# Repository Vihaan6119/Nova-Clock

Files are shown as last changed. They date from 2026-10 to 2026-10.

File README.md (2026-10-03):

# Nova Clock

Nova Clock is a custom desktop alarm clock built around a Seeed Studio XIAO ESP32-C3. It has a 2.25-inch TFT display, four mechanical keyboard switches, a piezo buzzer, a custom PCB, and a custom 3D-printed enclosure. The PCB, enclosure, and firmware were all designed as part of the same project so the electronics and the case fit together as one system.

## Why I made it

I wanted to build a project that was more than just a basic clock. I wanted to learn how a real hardware product comes together, from designing the PCB and enclosure to writing the firmware and planning how the final device would actually be used.
I also wanted the clock to be something I could keep improving later, especially the display styles, alarms, sounds, and the way it can be configured from another device.

## Project

The final design uses a custom PCB with the XIAO ESP32-C3 as the main controller. The four switches are used for local controls, while the TFT is used for the clock and other information. The buzzer provides startup and alarm sounds.

The enclosure was designed around the PCB so the board can be mounted securely while still leaving access to the USB port, display, switches, and buzzer. The display is held in place with a separate retainer so it can be removed without having to glue it into the case.

## How I planned the firmware

The firmware is included in the repository as a working prototype for the hardware design. The main idea is:

- show a short Nova Clock startup animation
- play a startup beep
- display the current time
- use the buttons for local clock and alarm controls
- store alarm settings on the ESP32-C3
- connect the clock to Wi-Fi
- provide a local web interface for changing alarm and display settings
- support different display styles and alarm sound patterns

The physical hardware is not available while the firmware was being made, so the final hardware behavior will be verified after the components arrive.

## Project images

### Case fit

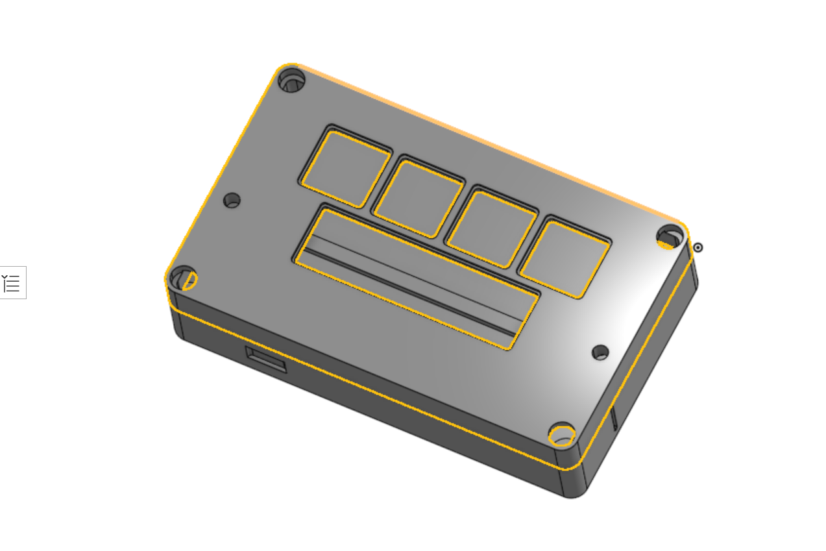
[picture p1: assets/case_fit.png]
Nova Clock Case Fit


### PCB

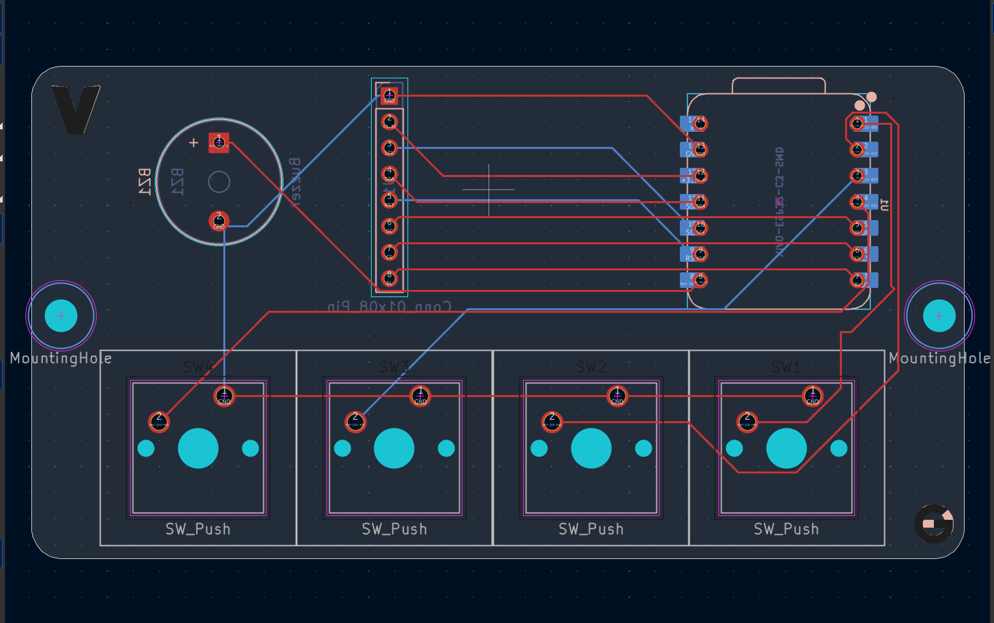
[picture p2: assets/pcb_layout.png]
Nova Clock PCB


### Schematic / wiring

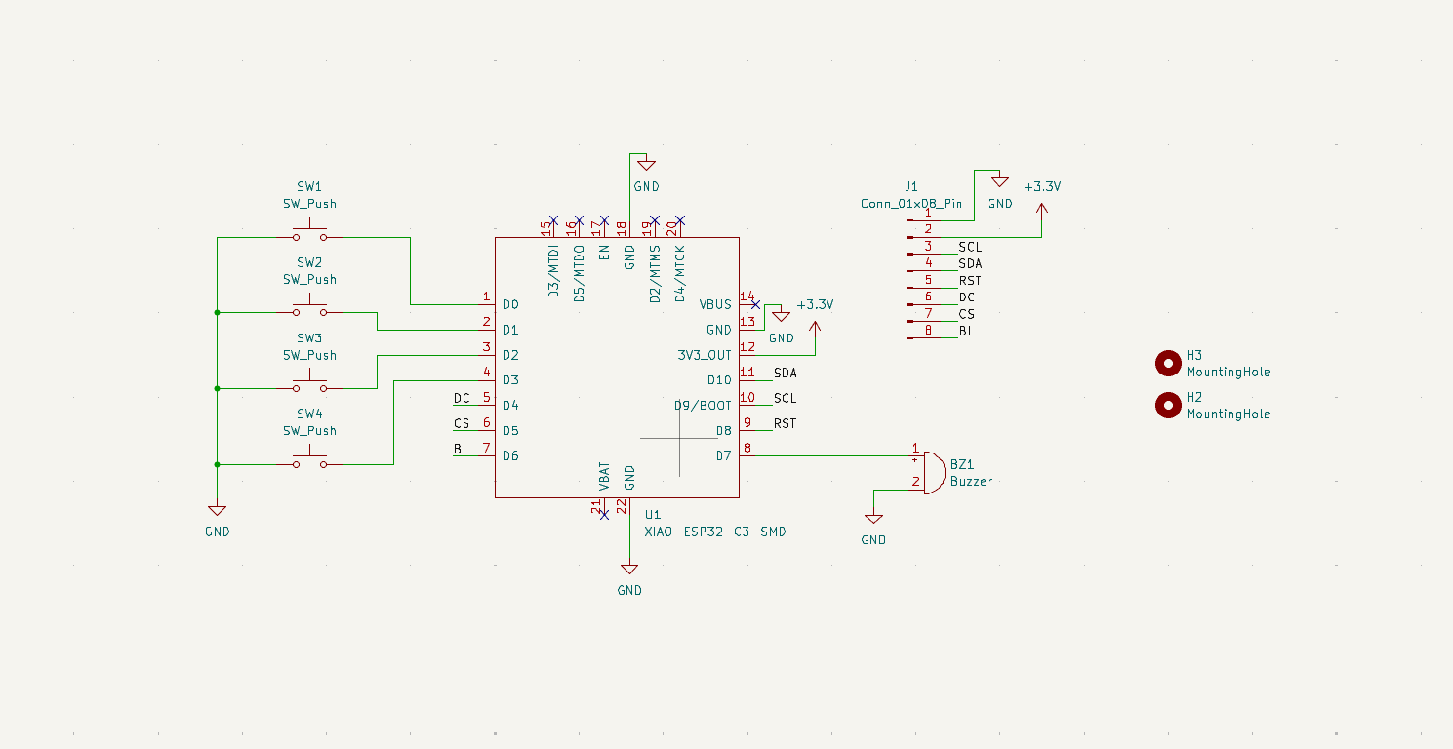
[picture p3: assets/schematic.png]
Nova Clock Schematic


The display is connected to the PCB using the 8-pin header and jumper wires included in the kit.

## Files

The repository contains the KiCad project and PCB source files, the CAD source and STEP assembly, the firmware, manufacturing files, and the project images.

- `PCB/` - KiCad project, schematic, PCB layout, and manufacturing files
- `CAD/` - enclosure source files and final STEP assembly
- `Firmware/` - Nova Clock firmware
- `Production/` - production/export files
- `assets/` - screenshots and project images

## Bill of Materials

| Component | Quantity Used | Quantity in Kit | Description | Link |
|---|---:|---:|---|---|
| Seeed Studio XIAO ESP32-C3 | 1 | 1 | Main microcontroller | [Seeed documentation](https://wiki.seeedstudio.com/XIAO_ESP32C3_Getting_Started/) |
| MX-style keyboard switch | 4 | 12 | Mechanical switches | [Switch specification](https://cdn.shopify.com/s/files/1/0565/8070/2297/files/SPEC-KS-3Y10B050NW-X1-Yellow_Switch.pdf?v=1675841028) |
| White blank DSA keycap | 4 | 12 | Keycaps for the switches | — |
| 1N4148 through-hole diode | 4 | 12 | Switch matrix diodes | [Vishay 1N4148 datasheet](https://www.vishay.com/docs/81857/1n4148.pdf) |
| 2.25-inch TFT display | 1 | 1 | Main clock display | — |
| 3.3 V piezo buzzer | 1 | 1 | Startup and alarm sound | — |
| 2.54 mm 8-pin male header | 1 | 1 | Display connector | — |
| 20 cm female-female jumper wire | 8 | 8 | Display wiring | — |
| M3x5x4 heat-set insert | 8 | 8 | Case, PCB, and display mounting | [Insert source](https://www.aliexpress.us/item/2255800046543591.html) |
| M3x8 screw | 4 | 4 | PCB/display-retainer mounting | — |
| M3x16 screw | 4 | 4 | Main enclosure screws | — |
| Custom 2-layer PCB | 1 | 1 | PCB designed in KiCad | [Project PCB](PCB/) |
| 3D-printed enclosure | 1 | 1 | Custom Nova Clock case | [Project CAD](CAD/) |

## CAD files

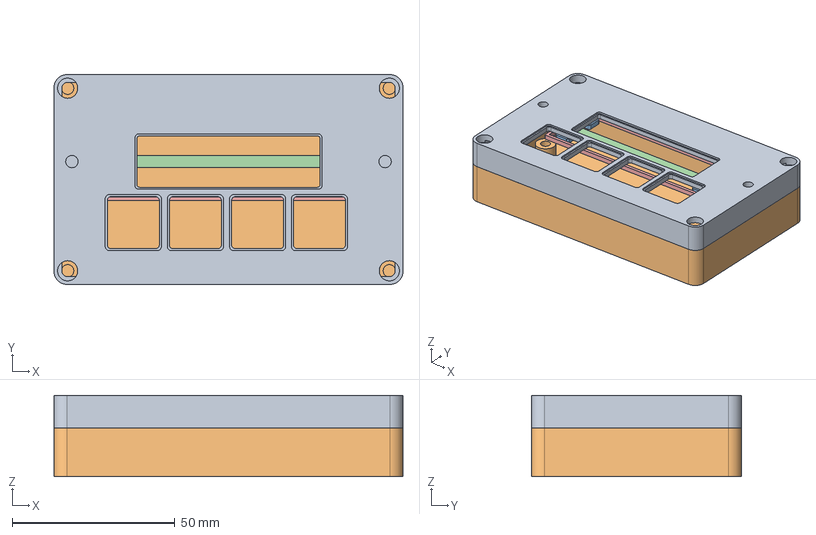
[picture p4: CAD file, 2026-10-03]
CAD/Nova-clock Final Assembly.step
107.4 x 64.6 x 25.0 mm

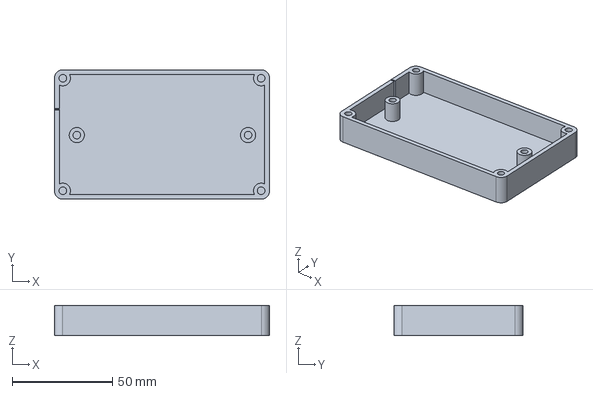
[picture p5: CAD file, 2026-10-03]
CAD/Nova_Clock_Final_Base.step
107.4 x 64.6 x 15.0 mm

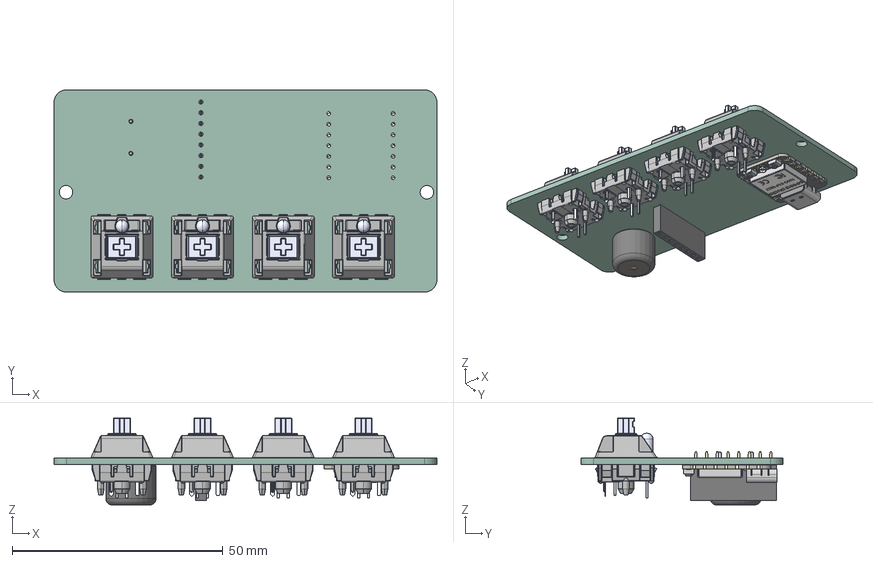
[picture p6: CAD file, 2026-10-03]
Production/Nova Clock-V2.step
90.8 x 48.0 x 20.6 mm
MX Öá °´¼ü¡ä_¨¹___¡§1 x 4
MX ס סͥ¨¢¨¬_¡§¡顧__ x 4
MXס ϞñLEDLEDLED x 4
MXÖá ÖáÌå µ×²¿ ¦Ì¡Á2__Ä¬ÈÏ_¨¢2____¨¨_ x 4
֫½ğ__Ĭɏ__¨¨_ x 4
BOSS-EXTRUDE14_8_
BOSS-EXTRUDE7_4_
BOSS-EXTRUDE7_3_
BOSS-EXTRUDE14_4_
BOSS-EXTRUDE14_2_
BOSS-EXTRUDE14_11_
BOSS-EXTRUDE7_7_
BOSS-EXTRUDE14_9_
BOSS-EXTRUDE14_3_
BOSS-EXTRUDE14_7_
MIRROR2
BOSS-EXTRUDE14_5_
BOSS-EXTRUDE14_12_
BOSS-EXTRUDE7_8_
BOSS-EXTRUDE7_1_
BOSS-EXTRUDE14_10_
BOSS-EXTRUDE7_9_
BOSS-EXTRUDE14_6_
BOSS-EXTRUDE14_1_
BOSS-EXTRUDE7_6_
BOSS-EXTRUDE7_2_
CUT-EXTRUDE5
BOSS-EXTRUDE7_5_
U.FL Connector v1
Button (1) x 2
Shield
Buzzer_12x95RM76
PinSocket_1x08_P2.54mm_Vertical
Nova Clock_PCB

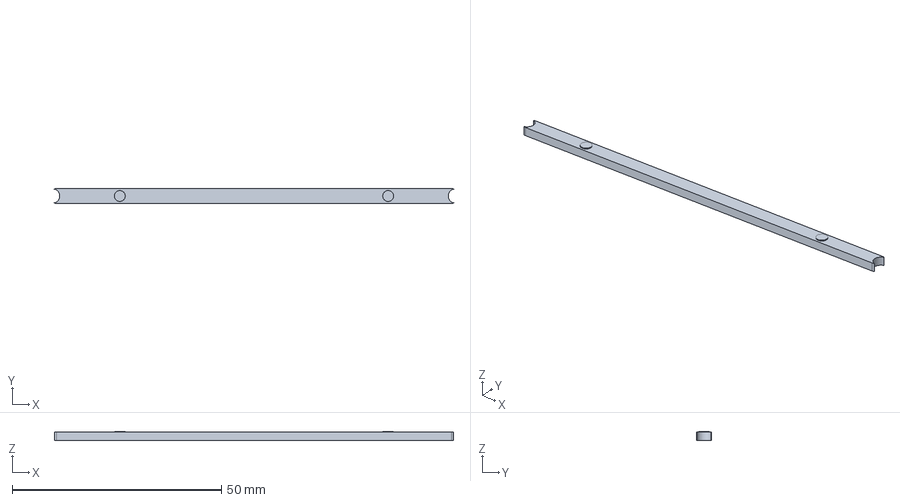
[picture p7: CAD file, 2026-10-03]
CAD/Nova_Clock_Final_Display_Retainer.step
95.4 x 3.60 x 2.20 mm

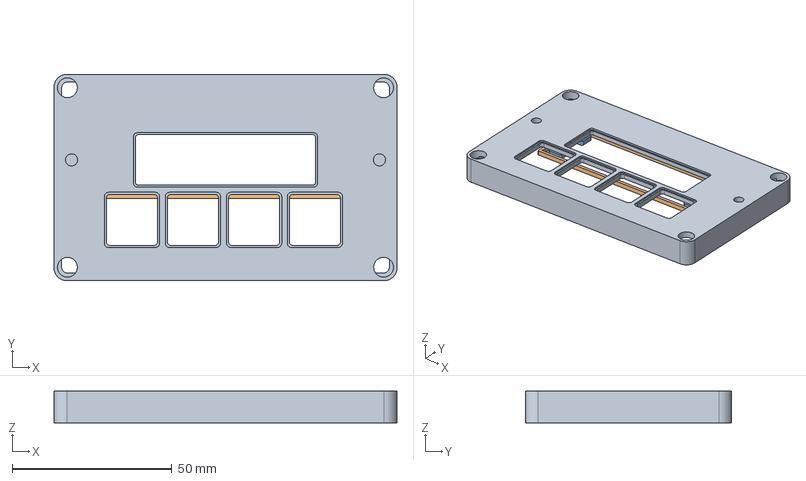
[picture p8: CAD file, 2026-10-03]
CAD/Nova_Clock_Final_Lid.step
107.4 x 64.6 x 10.0 mm

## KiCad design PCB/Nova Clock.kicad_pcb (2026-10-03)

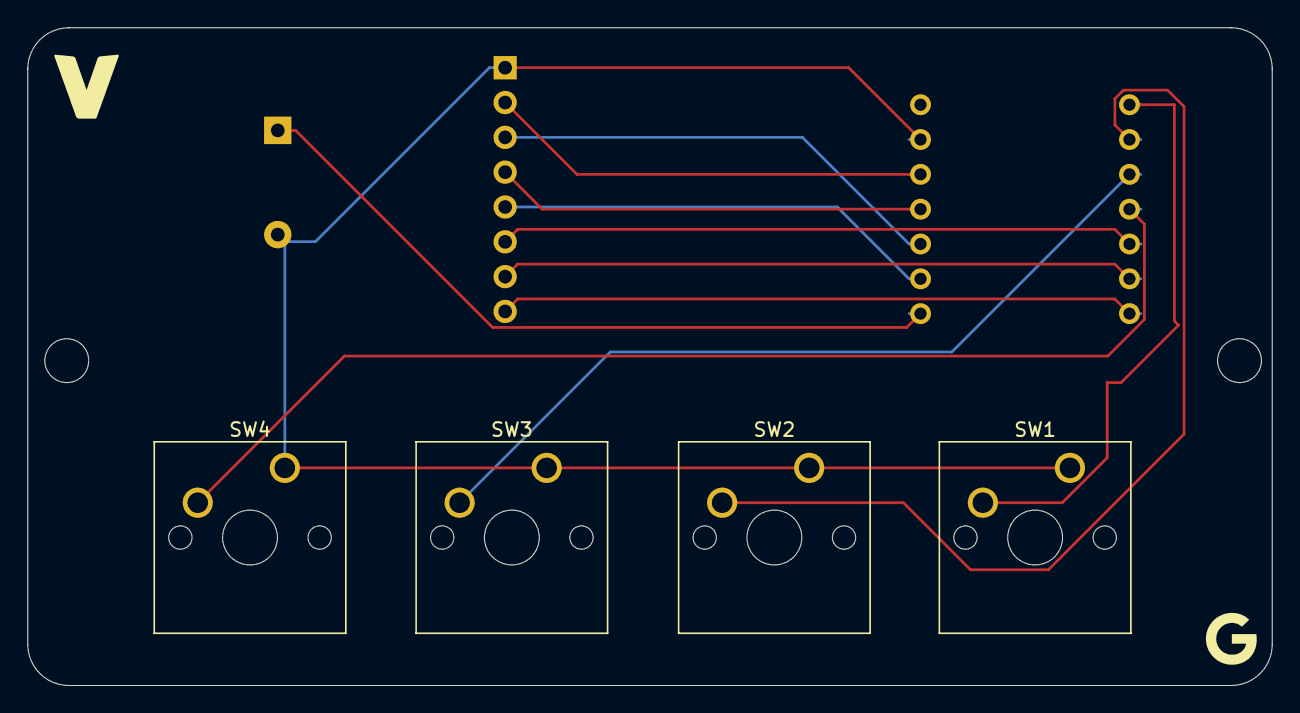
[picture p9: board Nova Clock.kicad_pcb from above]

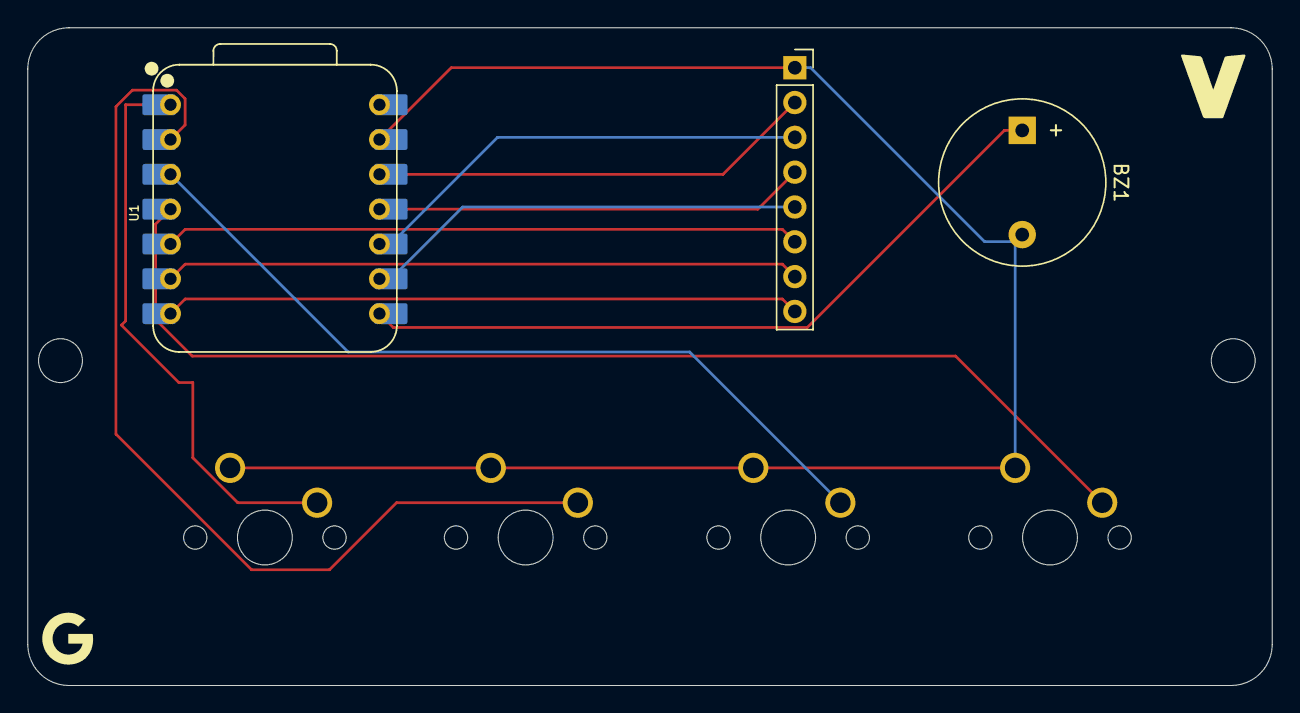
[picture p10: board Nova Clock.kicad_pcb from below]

Board: 2 copper layers, 90.8 x 48.0 mm, 9 parts (3 on the bottom side), 13 nets.

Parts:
BZ1: Buzzer; Buzzer_12x9.5RM7.6
H2, H3: MountingHole; MountingHole_3.2mm_M3
J1: Conn_01x08_Pin; PinSocket_1x08_P2.54mm_Vertical
SW1, SW2, SW3, SW4: SW_Push; SW_Cherry_MX_1.00u_PCB
U1: XIAO-ESP32-C3-SMD; XIAO-ESP32-C3-DIP

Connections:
+3.3V: J1.2, U1.12 (3V3_OUT)
/BL: J1.8, U1.7 (D6)
/CS: J1.7, U1.6 (D5)
/DC: J1.6, U1.5 (D4)
/RST: J1.5, U1.9 (D8)
/SCL: J1.3, U1.10 (D9/BOOT)
/SDA: J1.4, U1.11 (D10)
GND: BZ1.2 (-), J1.1, SW1.1, SW2.1, SW3.1, SW4.1, U1.13 (GND)
unnamed: BZ1.1 (+), U1.8 (D7)
unnamed: SW1.2, U1.1 (D0)
unnamed: SW2.2, U1.2 (D1)
unnamed: SW3.2, U1.3 (D2)
unnamed: SW4.2, U1.4 (D3)

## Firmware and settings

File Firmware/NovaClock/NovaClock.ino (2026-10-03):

#include <Arduino.h>
#include <WiFi.h>
#include <WebServer.h>
#include <ESPmDNS.h>
#include <Preferences.h>
#include <time.h>
#include <SPI.h>
#include <Adafruit_GFX.h>
#include <Adafruit_ST7789.h>


// Hardware configuration
namespace Pins {
  constexpr uint8_t SW1 = D0; // GPIO2
  constexpr uint8_t SW2 = D1; // GPIO3

  constexpr uint8_t SW3 = D2; // GPIO4 
  constexpr uint8_t SW4 = D3; // GPIO5 

  constexpr uint8_t BUZZER = D4; // GPIO6 

  constexpr uint8_t TFT_BL  = D5;  // GPIO7 
  constexpr uint8_t TFT_DC  = D6;  // GPIO21 
  constexpr uint8_t TFT_RST = D7;  // GPIO20 
  constexpr uint8_t TFT_SCK = D8;  // GPIO8  
  constexpr uint8_t TFT_CS  = D9;  // GPIO9  
  constexpr uint8_t TFT_MOSI = D10; // GPIO10 
}

constexpr uint16_t TFT_NATIVE_W = 240;
constexpr uint16_t TFT_NATIVE_H = 320;
constexpr uint8_t TFT_ROTATION = 1; // landscape; change to 0/1/2/3 as required

// Firmware constants
constexpr uint8_t MAX_ALARMS = 8;
constexpr uint32_t BUTTON_DEBOUNCE_MS = 60;
constexpr uint32_t LONG_PRESS_MS = 900;
constexpr uint32_t DISPLAY_REFRESH_MS = 500;
constexpr int DEFAULT_TZ_MINUTES = 240; // UTC+04:00
constexpr uint16_t DEFAULT_BEEP_HZ = 1800;
constexpr uint8_t DEFAULT_BRIGHTNESS = 210;
constexpr char AP_NAME[] = "NovaClock-Setup";
constexpr char AP_PASSWORD[] = "novaclock"; // local setup AP only
constexpr char MDNS_NAME[] = "novaclock";

WebServer server(80);
Preferences prefs;
Adafruit_ST7789 tft(&SPI, Pins::TFT_CS, Pins::TFT_DC, Pins::TFT_RST);

// Data model
struct Alarm {
  bool enabled = false;
  uint8_t hour = 7;
  uint8_t minute = 0;
  char label[21] = "Alarm";
};

Alarm alarms[MAX_ALARMS];

String displayStyle = "digital";    // digital, minimal, info
String displayFont = "large";       // small, large, xl
String soundPattern = "double";     // beep, double, triple, pulse
String deviceName = "Nova Clock";
int tzMinutes = DEFAULT_TZ_MINUTES;
uint8_t brightness = DEFAULT_BRIGHTNESS;
bool nightMode = false;
bool showAlarmList = false;

String lastAlarmMinute = "";
int activeAlarmIndex = -1;
uint32_t lastDisplayDraw = 0;
uint32_t lastWiFiRetry = 0;

// Non-blocking buzzer sequencer
struct ToneStep {
  uint16_t frequency;
  uint16_t duration;
  uint16_t gap;
};

ToneStep soundSteps[4];
uint8_t soundStepCount = 0;
uint8_t soundStepIndex = 0;
bool soundPlaying = false;
uint32_t soundStepStarted = 0;
bool soundInGap = false;
uint16_t alarmSoundFrequency = DEFAULT_BEEP_HZ;

void stopTone() {
  ledcWriteTone(Pins::BUZZER, 0);
}

void startTone(uint16_t frequency) {
  if (frequency == 0) {
    stopTone();
    return;
  }
  ledcWriteTone(Pins::BUZZER, frequency);
}

void startSoundPattern(const String &pattern, uint16_t frequency) {
  alarmSoundFrequency = constrain(frequency, 200, 5000);
  soundStepCount = 0;

  if (pattern == "triple") {
    soundSteps[0] = {alarmSoundFrequency, 100, 80};
    soundSteps[1] = {alarmSoundFrequency, 100, 80};
    soundSteps[2] = {alarmSoundFrequency, 180, 120};
    soundStepCount = 3;
  } else if (pattern == "pulse") {
    soundSteps[0] = {alarmSoundFrequency, 70, 150};
    soundSteps[1] = {alarmSoundFrequency, 260, 100};
    soundStepCount = 2;
  } else if (pattern == "beep") {
    soundSteps[0] = {alarmSoundFrequency, 220, 120};
    soundStepCount = 1;
  } else {
    soundSteps[0] = {alarmSoundFrequency, 120, 90};
    soundSteps[1] = {alarmSoundFrequency, 220, 120};
    soundStepCount = 2;
  }

  soundStepIndex = 0;
  soundPlaying = true;
  soundInGap = false;
  soundStepStarted = millis();
  startTone(soundSteps[0].frequency);
  Serial.printf("[BUZZER] pattern=%s freq=%u Hz\n", pattern.c_str(), alarmSoundFrequency);
}

void serviceSound() {
  if (!soundPlaying || soundStepIndex >= soundStepCount) return;

  const uint32_t now = millis();
  const ToneStep &step = soundSteps[soundStepIndex];

  if (!soundInGap && now - soundStepStarted >= step.duration) {
    stopTone();
    soundInGap = true;
    soundStepStarted = now;
  }

  if (soundInGap && now - soundStepStarted >= step.gap) {
    ++soundStepIndex;
    if (soundStepIndex >= soundStepCount) {
      soundPlaying = false;
      stopTone();
      return;
    }
    soundInGap = false;
    soundStepStarted = now;
    startTone(soundSteps[soundStepIndex].frequency);
  }
}

// Persistence
String alarmKey(uint8_t index, const char *field) {
  return "a" + String(index) + field;
}

void saveSettings() {
  prefs.begin("nova", false);
  prefs.putString("style", displayStyle);
  prefs.putString("font", displayFont);
  prefs.putString("sound", soundPattern);
  prefs.putString("name", deviceName);
  prefs.putInt("tzmin", tzMinutes);
  prefs.putUChar("bright", brightness);
  prefs.putBool("night", nightMode);

  for (uint8_t i = 0; i < MAX_ALARMS; ++i) {
    prefs.putBool(alarmKey(i, "e").c_str(), alarms[i].enabled);
    prefs.putUChar(alarmKey(i, "h").c_str(), alarms[i].hour);
    prefs.putUChar(alarmKey(i, "m").c_str(), alarms[i].minute);
    prefs.putString(alarmKey(i, "l").c_str(), alarms[i].label);
  }
  prefs.end();
}

void loadSettings() {
  prefs.begin("nova", true);
  displayStyle = prefs.getString("style", "digital");
  displayFont = prefs.getString("font", "large");
  soundPattern = prefs.getString("sound", "double");
  deviceName = prefs.getString("name", "Nova Clock");
  tzMinutes = prefs.getInt("tzmin", DEFAULT_TZ_MINUTES);
  brightness = prefs.getUChar("bright", DEFAULT_BRIGHTNESS);
  nightMode = prefs.getBool("night", false);

  alarms[0].enabled = prefs.getBool("a0e", true);
  alarms[0].hour = prefs.getUChar("a0h", 7);
  alarms[0].minute = prefs.getUChar("a0m", 0);
  String defaultLabel = prefs.getString("a0l", "Morning");
  strncpy(alarms[0].label, defaultLabel.c_str(), sizeof(alarms[0].label) - 1);

  for (uint8_t i = 1; i < MAX_ALARMS; ++i) {
    alarms[i].enabled = prefs.getBool(alarmKey(i, "e").c_str(), false);
    alarms[i].hour = prefs.getUChar(alarmKey(i, "h").c_str(), 8);
    alarms[i].minute = prefs.getUChar(alarmKey(i, "m").c_str(), 0);
    String label = prefs.getString(alarmKey(i, "l").c_str(), "Alarm");
    strncpy(alarms[i].label, label.c_str(), sizeof(alarms[i].label) - 1);
    alarms[i].label[sizeof(alarms[i].label) - 1] = '\0';
  }
  prefs.end();
}

// Time
void configureClock() {
  configTime(tzMinutes * 60L, 0, "pool.ntp.org", "time.nist.gov", "time.google.com");
}

bool readLocalTime(struct tm &t) {
  return getLocalTime(&t, 20);
}

String currentTimeString() {
  struct tm t;
  if (!readLocalTime(t)) return "--:--:--";
  char buf[9];
  strftime(buf, sizeof(buf), "%H:%M:%S", &t);
  return String(buf);
}


// TFT UI
void setBacklight() {
  uint8_t level = nightMode ? 25 : brightness;
  ledcWrite(Pins::TFT_BL, level);
}

void centerText(const String &text, int16_t y, uint8_t size, uint16_t color = ST77XX_WHITE) {
  int16_t x1, y1;
  uint16_t w, h;
  tft.setTextSize(size);
  tft.getTextBounds(text, 0, y, &x1, &y1, &w, &h);
  int16_t x = (tft.width() - (int16_t)w) / 2;
  tft.setCursor(x, y);
  tft.setTextColor(color);
  tft.print(text);
}

void drawBootAnimation() {
  tft.fillScreen(ST77XX_BLACK);
  centerText("NOVA", 22, 3, 0xFFE0);
  centerText("CLOCK", 58, 3, 0xFFE0);
  tft.drawLine(40, 99, tft.width() - 40, 99, 0xFFE0);
  for (uint8_t i = 0; i < 5; ++i) {
    tft.fillCircle(tft.width() / 2 - 20 + i * 10, 120, 3, 0xFFE0);
    delay(70);
  }
  delay(250);
}

uint8_t clockTextSize() {
  if (displayFont == "small") return 3;
  if (displayFont == "xl") return 5;
  return 4;
}

void drawClockFace() {
  struct tm t;
  tft.fillScreen(ST77XX_BLACK);

  if (!readLocalTime(t)) {
    centerText("SYNCING TIME", 48, 2, 0xFFE0);
    centerText(WiFi.status() == WL_CONNECTED ? "Wi-Fi connected" : "No network", 82, 1, ST77XX_WHITE);
    return;
  }

  char hm[6];
  strftime(hm, sizeof(hm), "%H:%M", &t);
  char sec[3];
  strftime(sec, sizeof(sec), "%S", &t);

  if (displayStyle == "minimal") {
    centerText(String(hm), 38, clockTextSize(), 0xFFE0);
    centerText(String(sec), 88, 2, ST77XX_WHITE);
  } else if (displayStyle == "info") {
    centerText(String(hm), 26, clockTextSize(), 0xFFE0);
    char day[32];
    strftime(day, sizeof(day), "%a, %d %b", &t);
    centerText(String(day), 80, 2, ST77XX_WHITE);
    String wifi = WiFi.status() == WL_CONNECTED ? "Wi-Fi" : "AP mode";
    centerText(wifi, 108, 1, 0x7BEF);
  } else {
    centerText(String(hm), 30, clockTextSize(), 0xFFE0);
    centerText(String(":"), 31, clockTextSize(), 0xFFE0);
    String secText = String(sec) + " s";
    centerText(secText, 92, 1, ST77XX_WHITE);
  }

  uint8_t active = 0;
  for (const auto &alarm : alarms) if (alarm.enabled) ++active;
  String alarmLine = String(active) + " active alarm" + (active == 1 ? "" : "s");
  centerText(alarmLine, tft.height() - 24, 1, 0x7BEF);
}

void drawAlarmList() {
  tft.fillScreen(ST77XX_BLACK);
  centerText("ACTIVE ALARMS", 8, 2, 0xFFE0);

  uint8_t row = 0;
  for (uint8_t i = 0; i < MAX_ALARMS; ++i) {
    if (!alarms[i].enabled) continue;
    char tm[6];
    snprintf(tm, sizeof(tm), "%02u:%02u", alarms[i].hour, alarms[i].minute);
    String line = String(tm) + "  " + String(alarms[i].label);
    tft.setTextSize(1);
    tft.setTextColor(ST77XX_WHITE);
    tft.setCursor(10, 40 + row * 18);
    tft.print(line.substring(0, 32));
    if (++row >= 7) break;
  }

  if (row == 0) centerText("No active alarms", 58, 1, ST77XX_WHITE);
  tft.setTextSize(1);
  tft.setTextColor(0x7BEF);
  tft.setCursor(10, tft.height() - 16);
  tft.print("SW1: back");
}

void updateDisplay() {
  if (showAlarmList) drawAlarmList();
  else drawClockFace();
  lastDisplayDraw = millis();
}

void displayBegin() {
  SPI.begin(Pins::TFT_SCK, -1, Pins::TFT_MOSI, Pins::TFT_CS);
  tft.init(TFT_NATIVE_W, TFT_NATIVE_H);
  tft.setRotation(TFT_ROTATION);
  tft.fillScreen(ST77XX_BLACK);
  setBacklight();
}

// Alarm logic
void dismissCurrentAlarm() {
  if (activeAlarmIndex < 0) return;
  Serial.printf("[ALARM] Dismissed: %s\n", alarms[activeAlarmIndex].label);
  activeAlarmIndex = -1;
  soundPlaying = false;
  stopTone();
}

void triggerAlarm(uint8_t index) {
  activeAlarmIndex = index;
  showAlarmList = false;
  startSoundPattern(soundPattern, alarmSoundFrequency);
  Serial.printf("[ALARM] Triggered %s at %02u:%02u\n",
                alarms[index].label, alarms[index].hour, alarms[index].minute);
}

void serviceAlarms() {
  struct tm t;
  if (!readLocalTime(t)) return;

  char minuteKey[24];
  strftime(minuteKey, sizeof(minuteKey), "%Y-%m-%d %H:%M", &t);
  if (lastAlarmMinute == minuteKey) return;

  char hm[6];
  strftime(hm, sizeof(hm), "%H:%M", &t);

  for (uint8_t i = 0; i < MAX_ALARMS; ++i) {
    if (!alarms[i].enabled) continue;
    char alarmTime[6];
    snprintf(alarmTime, sizeof(alarmTime), "%02u:%02u", alarms[i].hour, alarms[i].minute);
    if (String(alarmTime) == String(hm)) {
      triggerAlarm(i);
      break;
    }
  }
  lastAlarmMinute = String(minuteKey);
}

// Buttons
struct ButtonState {
  uint8_t pin;
  bool lastLevel;
  uint32_t pressedAt;
  uint32_t changedAt;
};

ButtonState buttons[4] = {
  {Pins::SW1, HIGH, 0, 0},
  {Pins::SW2, HIGH, 0, 0},
  {Pins::SW3, HIGH, 0, 0},
  {Pins::SW4, HIGH, 0, 0},
};

void cycleDisplayStyle() {
  if (displayStyle == "digital") displayStyle = "minimal";
  else if (displayStyle == "minimal") displayStyle = "info";
  else displayStyle = "digital";
  saveSettings();
}

void handleButton(uint8_t number, bool longPress) {
  Serial.printf("[BUTTON] SW%u %s\n", number, longPress ? "LONG" : "SHORT");

  switch (number) {
    case 1:
      if (activeAlarmIndex >= 0) {
        dismissCurrentAlarm();
      } else {
        showAlarmList = !showAlarmList;
      }
      break;

    case 2:
      cycleDisplayStyle();
      break;

    case 3:
      if (activeAlarmIndex >= 0) {
        // acknowledge/dismiss the ringing alarm.
        dismissCurrentAlarm();
      } else {
        startSoundPattern(soundPattern, alarmSoundFrequency);
      }
      break;

    case 4:
      nightMode = !nightMode;
      setBacklight();
      saveSettings();
      break;
  }

  updateDisplay();
}

void serviceButtons() {
  const uint32_t now = millis();
  for (uint8_t i = 0; i < 4; ++i) {
    bool level = digitalRead(buttons[i].pin);
    if (level != buttons[i].lastLevel) {
      buttons[i].lastLevel = level;
      buttons[i].changedAt = now;
    }

    if (level == LOW && buttons[i].pressedAt == 0 && now - buttons[i].changedAt >= BUTTON_DEBOUNCE_MS) {
      buttons[i].pressedAt = now;
    }

    if (level == HIGH && buttons[i].pressedAt != 0 && now - buttons[i].changedAt >= BUTTON_DEBOUNCE_MS) {
      const uint32_t held = now - buttons[i].pressedAt;
      buttons[i].pressedAt = 0;
      handleButton(i + 1, held >= LONG_PRESS_MS);
    }
  }
}


// Web control
String jsonEscape(const String &input) {
  String out;
  out.reserve(input.length() + 4);
  for (size_t i = 0; i < input.length(); ++i) {
    const char c = input[i];
    if (c == '"' || c == '\\') out += '\\';
    if (c == '\n') out += "\\n";
    else out += c;
  }
  return out;
}

String statusJson() {
  String json = "{";
  json += "\"device\":\"" + jsonEscape(deviceName) + "\",";
  json += "\"time\":\"" + currentTimeString() + "\",";
  json += "\"wifi_connected\":" + String(WiFi.status() == WL_CONNECTED ? "true" : "false") + ",";
  json += "\"ip\":\"" + WiFi.localIP().toString() + "\",";
  json += "\"style\":\"" + displayStyle + "\",";
  json += "\"font\":\"" + displayFont + "\",";
  json += "\"sound\":\"" + soundPattern + "\",";
  json += "\"frequency\":" + String(alarmSoundFrequency) + ",";
  json += "\"timezone_minutes\":" + String(tzMinutes) + ",";
  json += "\"brightness\":" + String(brightness) + ",";
  json += "\"night_mode\":" + String(nightMode ? "true" : "false") + ",";
  json += "\"active_alarm_index\":" + String(activeAlarmIndex) + ",";
  json += "\"alarms\":[";

  for (uint8_t i = 0; i < MAX_ALARMS; ++i) {
    if (i) json += ',';
    char tm[6];
    snprintf(tm, sizeof(tm), "%02u:%02u", alarms[i].hour, alarms[i].minute);
    json += "{\"id\":" + String(i);
    json += ",\"enabled\":" + String(alarms[i].enabled ? "true" : "false");
    json += ",\"time\":\"" + String(tm) + "\"";
    json += ",\"label\":\"" + jsonEscape(String(alarms[i].label)) + "\"}";
  }
  json += "]}";
  return json;
}

void apiStatus() {
  server.send(200, "application/json", statusJson());
}

bool validTime(const String &value) {
  if (value.length() != 5 || value[2] != ':') return false;
  int h = value.substring(0, 2).toInt();
  int m = value.substring(3, 5).toInt();
  return h >= 0 && h <= 23 && m >= 0 && m <= 59;
}

void apiAlarm() {
  int id = server.arg("id").toInt();
  if (id < 0 || id >= MAX_ALARMS) {
    server.send(400, "application/json", "{\"error\":\"bad id\"}");
    return;
  }

  const String timeArg = server.arg("time");
  if (timeArg.length() && !validTime(timeArg)) {
    server.send(400, "application/json", "{\"error\":\"bad time\"}");
    return;
  }

  if (server.hasArg("enabled")) alarms[id].enabled = server.arg("enabled") == "1" || server.arg("enabled") == "true";
  if (timeArg.length()) {
    alarms[id].hour = timeArg.substring(0, 2).toInt();
    alarms[id].minute = timeArg.substring(3, 5).toInt();
  }
  if (server.hasArg("label")) {
    String label = server.arg("label");
    label.replace("<", "");
    label.replace(">", "");
    strncpy(alarms[id].label, label.c_str(), sizeof(alarms[id].label) - 1);
    alarms[id].label[sizeof(alarms[id].label) - 1] = '\0';
  }

  saveSettings();
  server.send(200, "application/json", "{\"ok\":true}");
  updateDisplay();
}

void apiSettings() {
  if (server.hasArg("style")) {
    const String s = server.arg("style");
    if (s == "digital" || s == "minimal" || s == "info") displayStyle = s;
  }
  if (server.hasArg("font")) {
    const String f = server.arg("font");
    if (f == "small" || f == "large" || f == "xl") displayFont = f;
  }
  if (server.hasArg("tz")) tzMinutes = constrain(server.arg("tz").toInt(), -12 * 60, 14 * 60);
  if (server.hasArg("brightness")) brightness = constrain(server.arg("brightness").toInt(), 10, 255);
  if (server.hasArg("night")) nightMode = server.arg("night") == "1" || server.arg("night") == "true";

  setBacklight();
  saveSettings();
  configureClock();
  server.send(200, "application/json", "{\"ok\":true}");
  updateDisplay();
}

void apiSound() {
  const String pattern = server.hasArg("pattern") ? server.arg("pattern") : soundPattern;
  if (pattern == "beep" || pattern == "double" || pattern == "triple" || pattern == "pulse") soundPattern = pattern;
  if (server.hasArg("freq")) alarmSoundFrequency = constrain(server.arg("freq").toInt(), 200, 5000);
  saveSettings();
  startSoundPattern(soundPattern, alarmSoundFrequency);
  server.send(200, "application/json", "{\"ok\":true}");
}

void apiButton() {
  int id = server.arg("n").toInt();
  if (id < 1 || id > 4) {
    server.send(400, "application/json", "{\"error\":\"bad button\"}");
    return;
  }
  handleButton(id, false);
  server.send(200, "application/json", "{\"ok\":true}");
}

void apiWifi() {
  if (!server.hasArg("ssid") || !server.hasArg("password")) {
    server.send(400, "application/json", "{\"error\":\"ssid and password required\"}");
    return;
  }

  prefs.begin("wifi", false);
  prefs.putString("ssid", server.arg("ssid"));
  prefs.putString("pass", server.arg("password"));
  prefs.end();

  server.send(200, "application/json", "{\"ok\":true,\"restarting\":true}");
  delay(400);
  ESP.restart();
}

const char INDEX_HTML[] PROGMEM = R"HTML(
<!doctype html>
<html lang="en">
<head>
<meta charset="utf-8">
<meta name="viewport" content="width=device-width,initial-scale=1">
<title>Nova Clock</title>
<style>
body{font-family:system-ui,sans-serif;background:#0b0f14;color:#eef2f7;margin:0;padding:20px}
main{max-width:820px;margin:auto}.card{background:#121922;border:1px solid #2b3645;border-radius:16px;padding:16px;margin:12px 0}
.grid{display:grid;grid-template-columns:repeat(auto-fit,minmax(240px,1fr));gap:12px}
button,input,select{font:inherit;border-radius:9px;border:1px solid #38475a;background:#0b1118;color:#fff;padding:9px;margin:4px}
button{cursor:pointer}.clock{font-size:56px;font-weight:800;letter-spacing:2px}.status{color:#9daabd}.alarm{display:flex;gap:6px;align-items:center;flex-wrap:wrap}
</style>
</head>
<body><main>
<div class="card"><div class="status">NOVA CLOCK LOCAL CONTROL</div><h1 id="name">Nova Clock</h1><div id="clock" class="clock">--:--:--</div><div id="wifi" class="status">Connecting…</div></div>
<div class="card"><h2>Alarms</h2><div id="alarms"></div></div>
<div class="grid">
<div class="card"><h2>Display</h2><label>Style <select id="style"><option value="digital">Digital</option><option value="minimal">Minimal</option><option value="info">Info</option></select></label><br><label>Scale <select id="font"><option value="small">Small</option><option value="large">Large</option><option value="xl">XL</option></select></label><br><label>Brightness <input id="brightness" type="range" min="10" max="255"></label><br><button onclick="saveDisplay()">Save display</button></div>
<div class="card"><h2>Sound</h2><select id="sound"><option value="beep">Beep</option><option value="double">Double</option><option value="triple">Triple</option><option value="pulse">Pulse</option></select><input id="freq" type="number" min="200" max="5000"><button onclick="testSound()">Test</button></div>
</div>
<div class="card"><h2>Buttons</h2><button onclick="press(1)">SW1</button><button onclick="press(2)">SW2</button><button onclick="press(3)">SW3</button><button onclick="press(4)">SW4</button></div>
<div class="card"><h2>Network setup</h2><input id="ssid" placeholder="Wi-Fi SSID"><input id="pass" type="password" placeholder="Wi-Fi password"><button onclick="saveWiFi()">Save & restart</button></div>
</main>
<script>
const $=id=>document.getElementById(id);
async function api(path,opts={}){const r=await fetch(path,opts);return r.json()}
function esc(s){return String(s).replace(/[&<>"']/g,c=>({'&':'&amp;','<':'&lt;','>':'&gt;','"':'&quot;',"'":'&#39;'}[c]))}
async function refresh(){
 const x=await api('/api/status');$('name').textContent=x.device;$('clock').textContent=x.time;
 $('wifi').textContent=x.wifi_connected?`Wi-Fi: ${x.ip} • http://${location.host}`:'Setup AP active • save Wi-Fi below';
 $('style').value=x.style;$('font').value=x.font;$('brightness').value=x.brightness;$('sound').value=x.sound;$('freq').value=x.frequency;
 let h='';x.alarms.forEach((a,i)=>{h+=`<div class="alarm"><input id="e${i}" type="checkbox" ${a.enabled?'checked':''}><input id="t${i}" type="time" value="${a.time}"><input id="l${i}" value="${esc(a.label)}"><button onclick="saveAlarm(${i})">Save</button></div>`});$('alarms').innerHTML=h;
}
async function saveAlarm(i){await api(`/api/alarm?id=${i}&enabled=${$('e'+i).checked?1:0}&time=${encodeURIComponent($('t'+i).value)}&label=${encodeURIComponent($('l'+i).value)}`,{method:'POST'});refresh()}
async function saveDisplay(){await api(`/api/settings?style=${$('style').value}&font=${$('font').value}&brightness=${$('brightness').value}`,{method:'POST'});refresh()}
async function testSound(){await api(`/api/sound?pattern=${$('sound').value}&freq=${$('freq').value}`,{method:'POST'})}
async function press(n){await api(`/api/button?n=${n}`,{method:'POST'});refresh()}
async function saveWiFi(){await api(`/api/wifi?ssid=${encodeURIComponent($('ssid').value)}&password=${encodeURIComponent($('pass').value)}`,{method:'POST'})}
refresh();setInterval(refresh,1000);
</script>
</body></html>
)HTML";
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
void loop() {
  server.handleClient();
  serviceButtons();
  serviceSound();
  serviceAlarms();
  serviceWiFi();

  if (millis() - lastDisplayDraw >= DISPLAY_REFRESH_MS) updateDisplay();
  delay(2);
}

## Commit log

2026-09-18 PCB and Case .step files
    [Nova Clock.step]
2026-09-21 The final submit which has all the components required.
    [Nova Clock.kicad_pcb, Nova Clock.kicad_sch, Nova Clock.step]
2026-10-03 Nova-Clock V2
    In this commit, there is new PCB design, new case, and new images also added with a new are better firmware
    [Nova Clock-V2.step, Nova Clock.kicad_pcb, Nova Clock.step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]
2026-10-06 added the BOM
    [BOM.csv]
2026-10-24 Revise Bill of Materials with BLARE Kit details
    Updated the Bill of Materials to include 'BLARE Kit' for each component and added pricing information for the PCB and enclosure.
2026-10-24 updated the BOM.csv
2026-10-24 Update assembly details in README.md
    Clarified assembly description and components in README.
2026-10-31 Refine assembly description in README.md
    Removed unnecessary details about the assembly process and clarified the final steps taken with the PCB enclosure.
2026-10-31 Update V3.5
    The biggest update is the enclosure update. also updated readme.
2026-10-31 Update README with assembly instructions and remove errors
    Removed outdated information about exporting .step files and clarified instructions for viewing the full assembly model.
2026-10-31 Fix component count in assembly description
    Corrected the number of assembled components from 4 to 3 in the README.
2026-11-06 Update V4
    Updated the Readme, make a big decision on soldering the wires instead of connecting them with jumper wires, and updated the step files
